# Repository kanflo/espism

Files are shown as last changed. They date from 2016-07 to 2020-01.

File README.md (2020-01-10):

# Espism

This repo contins schematics and code to build a low cost ISM radio to wifi gateway.

Look at [hardware/v4](https://github.com/kanflo/espism/tree/master/hardware/v4) for the hardware and [verification](https://github.com/kanflo/espism/tree/master/verification) for the software used to do hardware verification. The directory [mqtt_sniffer](https://github.com/kanflo/espism/tree/master/mqtt_sniffer) contains an ISM to MQTT sniffer. Blog post [is here](http://johan.kanflo.com/bridging-ism-radio-and-wifi-for-lunch-money/).

#### Building

```
git clone https://github.com/kanflo/espism.git
cd espism
git submodule init && git submodule update
cd mqtt_sniffer
vi esp-open-rtos/include/private_ssid_config.h # Fix wifi credentials
make && make flash
```

Wifi credentials, in case you did not know, are written to `esp-open-rtos/include/private_ssid_config.h` as 

```
#define WIFI_SSID "your ssid"
#define WIFI_PASS "your key"
```

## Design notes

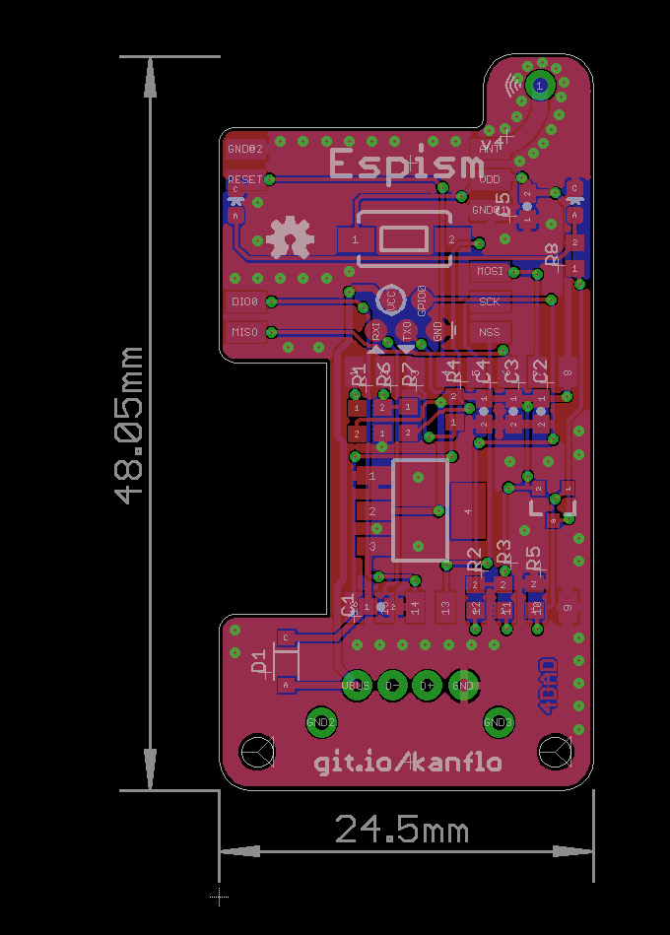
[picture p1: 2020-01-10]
hardware/v4/espism-v4.png

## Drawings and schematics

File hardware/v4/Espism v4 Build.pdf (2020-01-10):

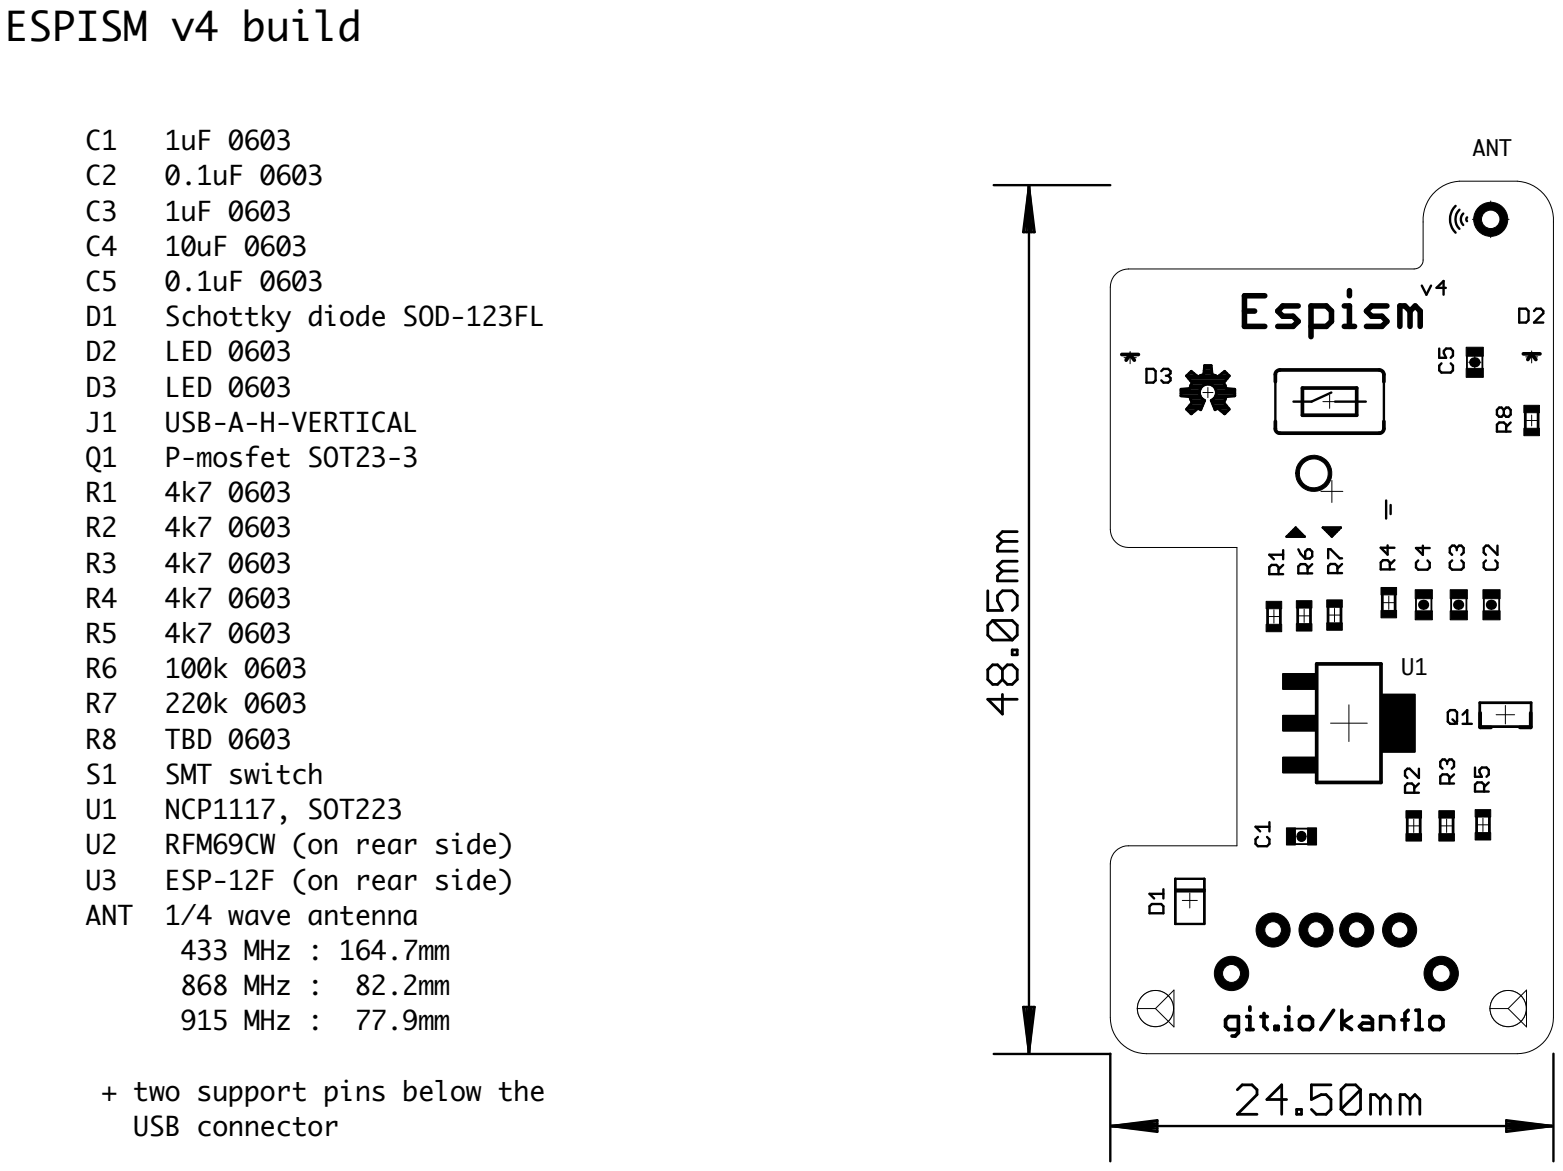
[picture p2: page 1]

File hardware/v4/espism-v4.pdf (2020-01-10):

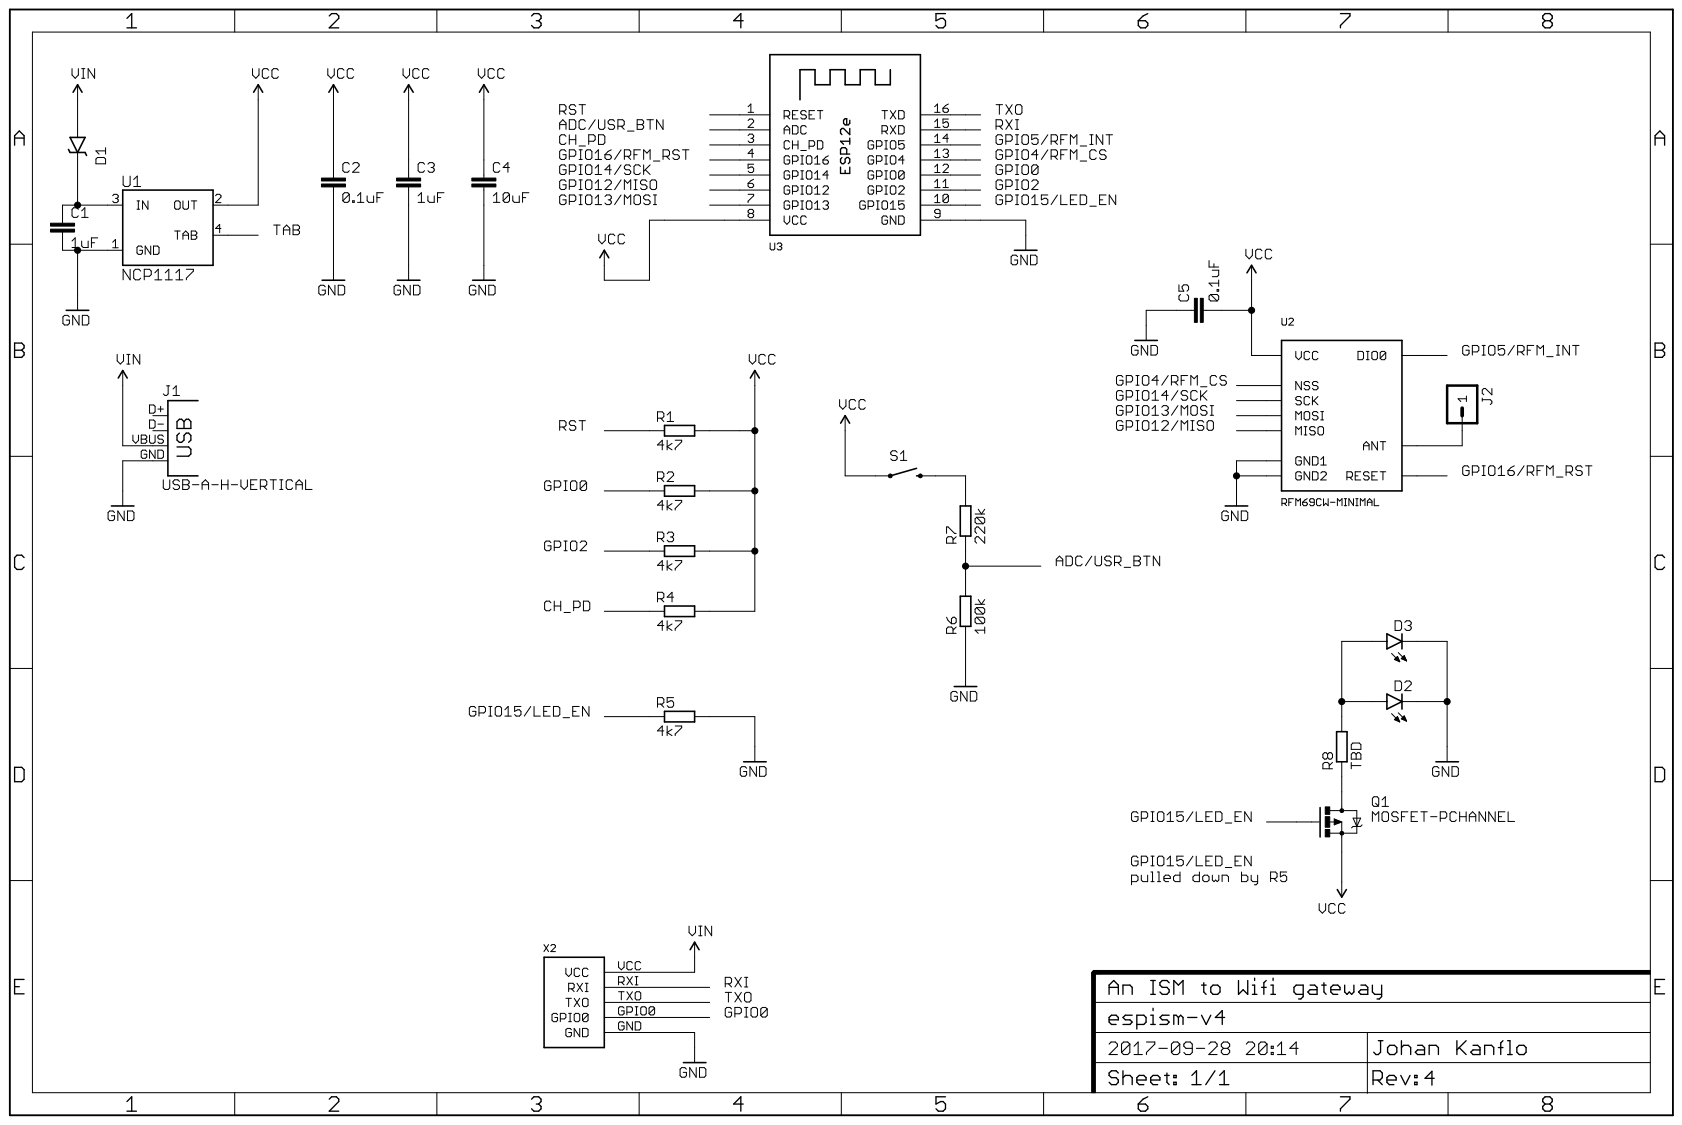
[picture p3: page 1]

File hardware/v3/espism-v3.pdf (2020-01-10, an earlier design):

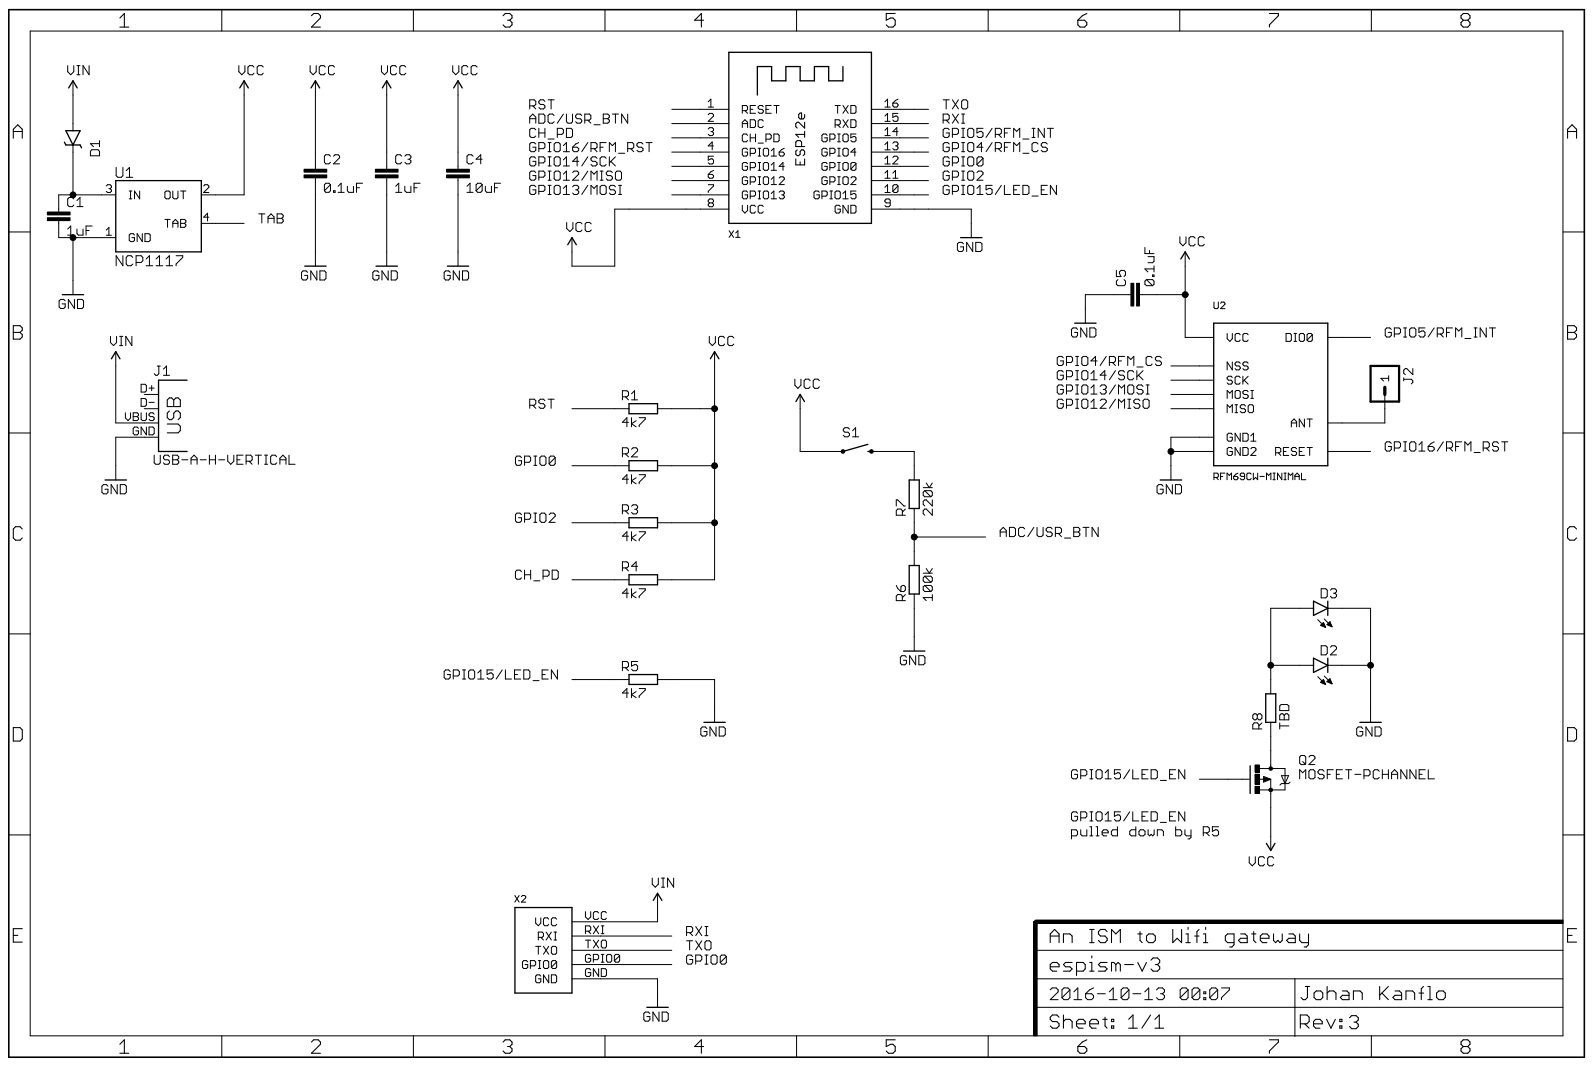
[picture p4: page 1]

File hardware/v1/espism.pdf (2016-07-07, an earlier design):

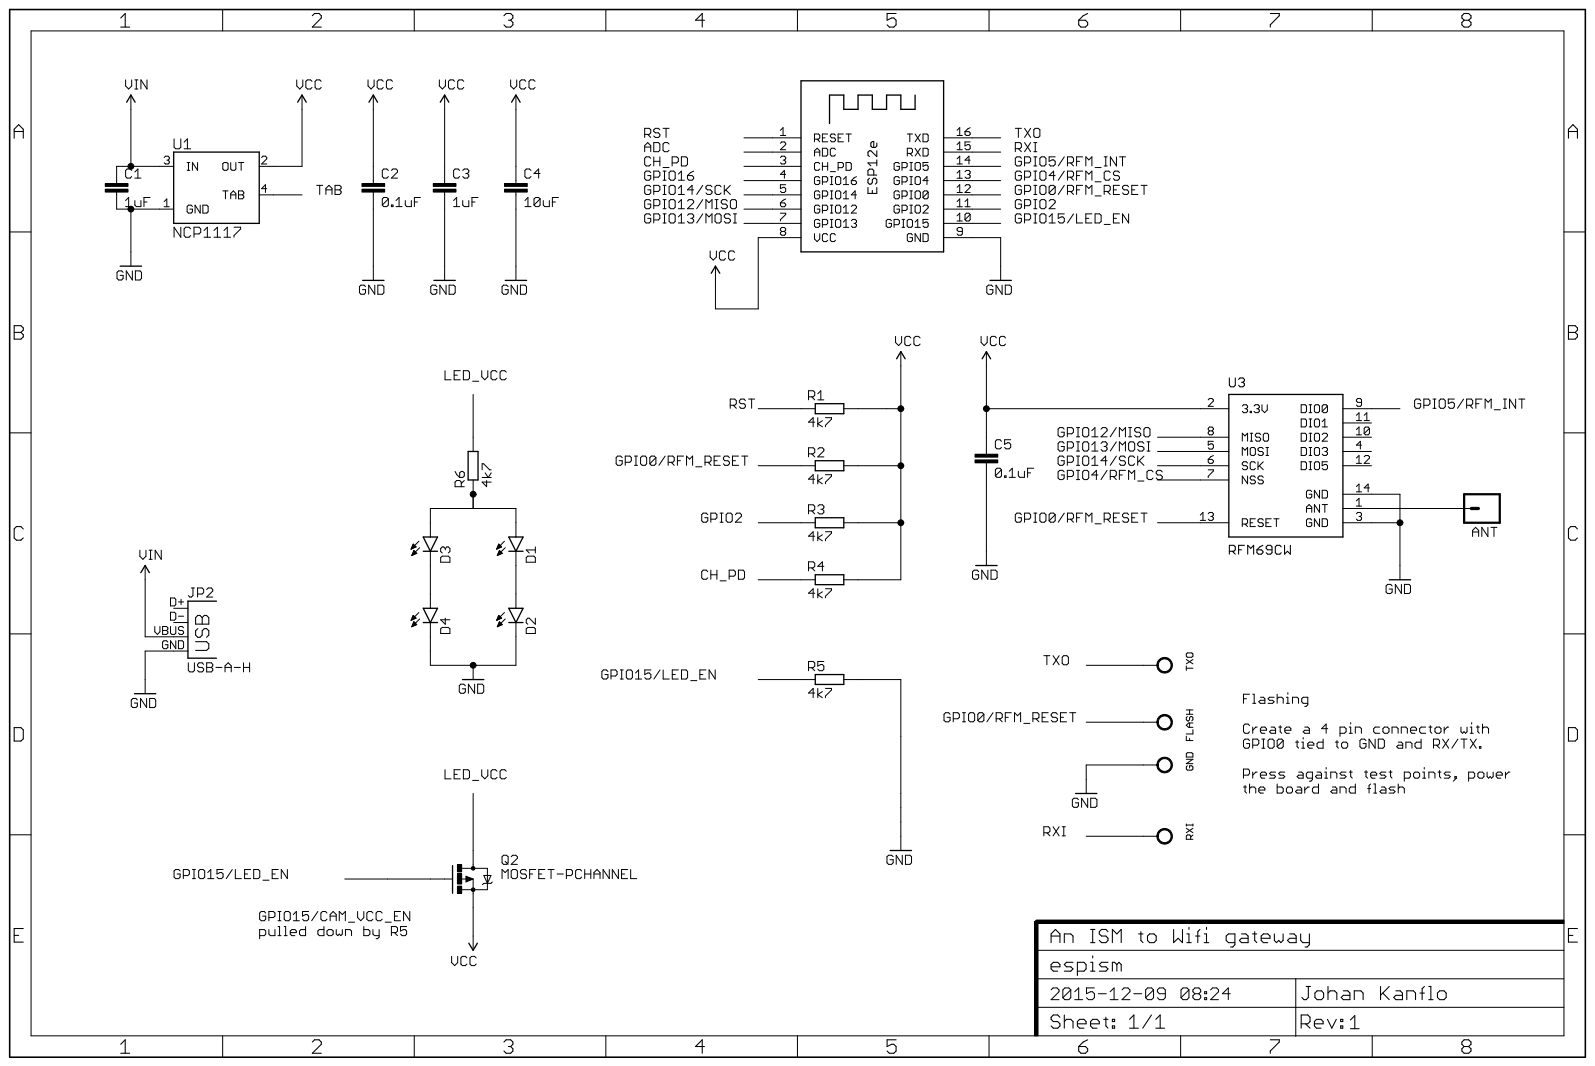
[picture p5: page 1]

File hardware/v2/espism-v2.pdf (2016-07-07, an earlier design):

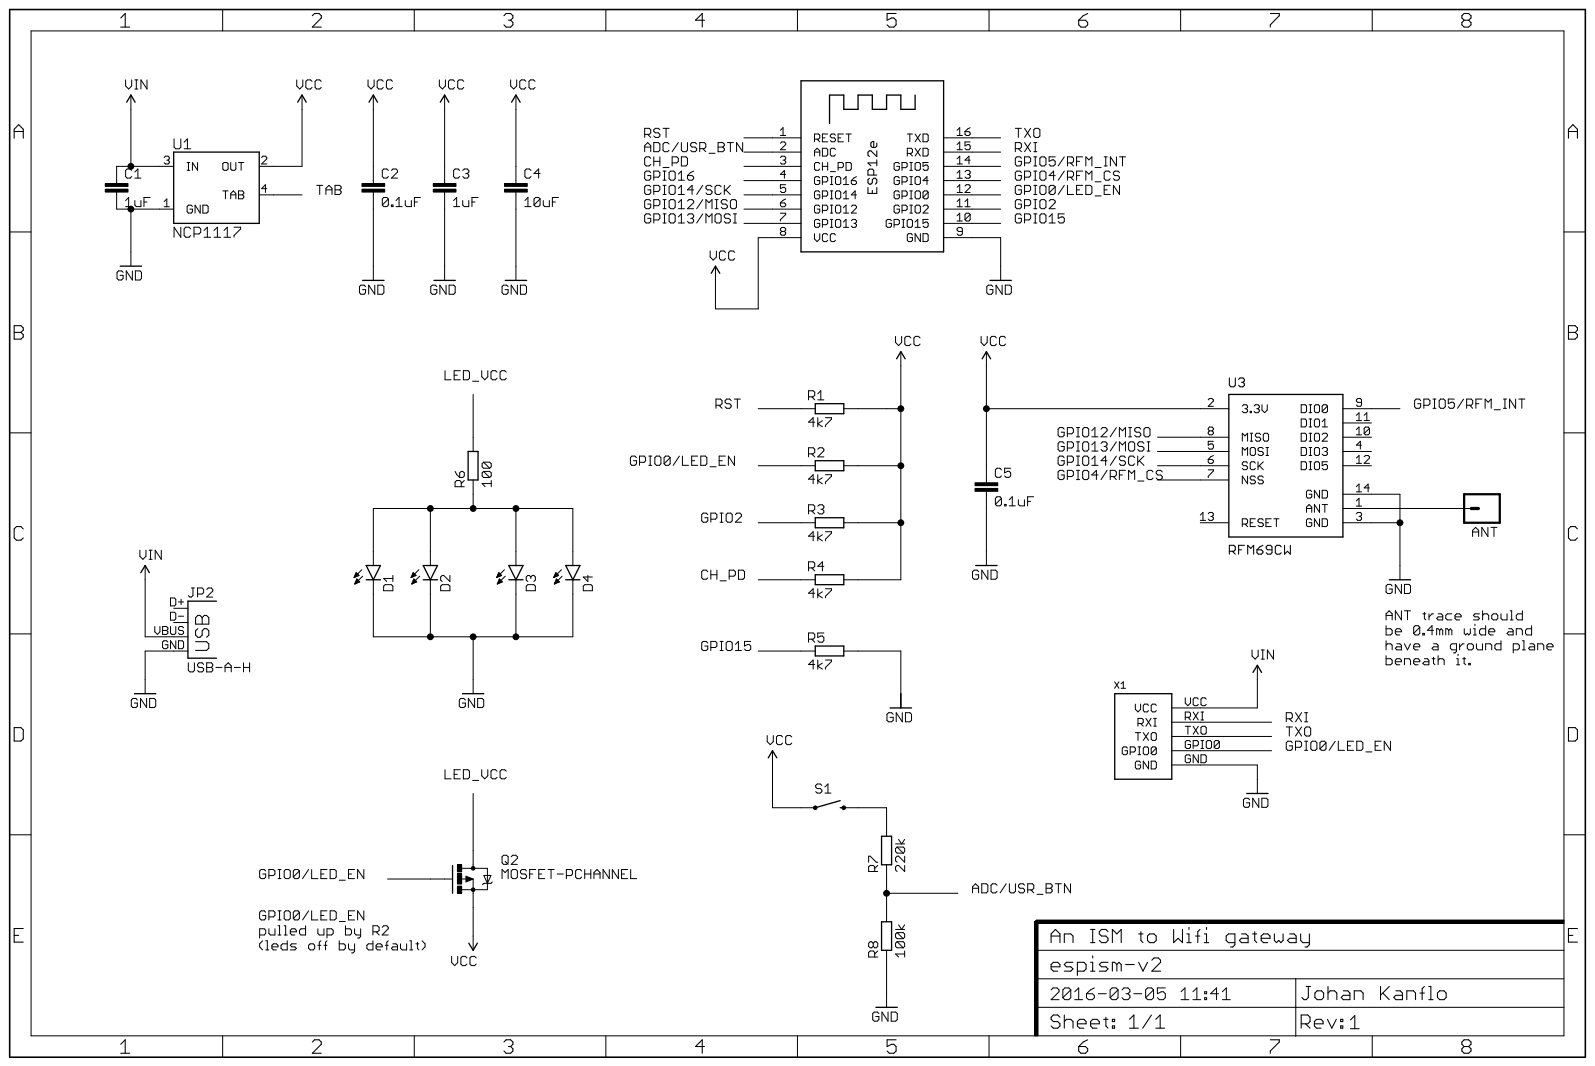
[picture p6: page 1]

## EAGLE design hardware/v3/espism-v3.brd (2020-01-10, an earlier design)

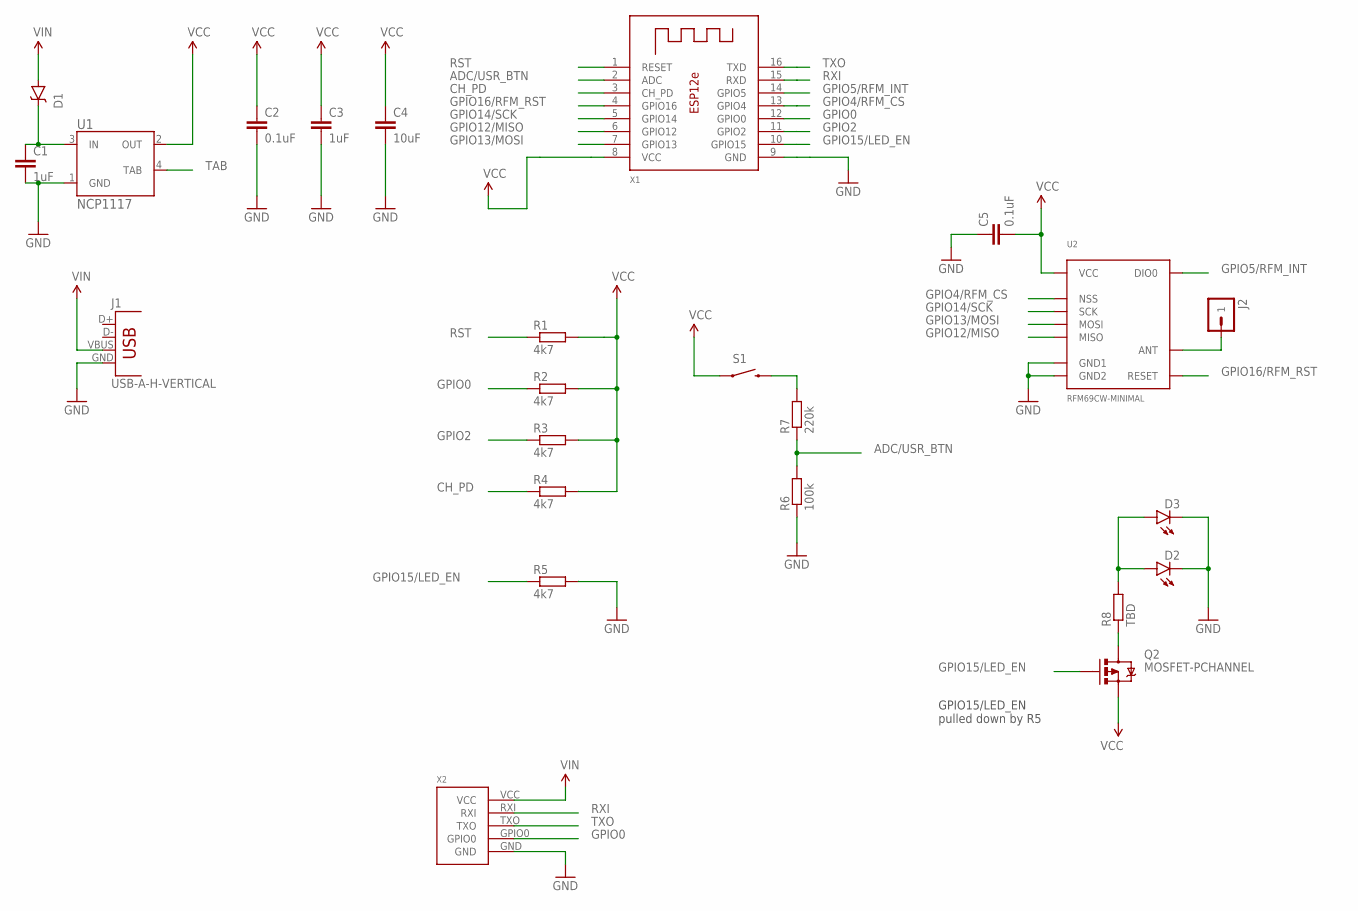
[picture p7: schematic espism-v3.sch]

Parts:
C1, C3: 1uF; 0603-CAP
C2, C5: 0.1uF; 0603-CAP
C4: 10uF; 0603-CAP
D1: DIODE-SCHOTTKYSOD-123FL; SOD-123FL
D2, D3: LED0603; LED-0603
J1: USB-A-H-VERTICAL
J2: M01-ANTENNA; 1X01-ANTENNA
Q2: MOSFET-PCHANNEL; SOT23-3
R1, R2, R3, R4, R5: 4k7; R0603
R6: 100k; R0603
R7: 220k; R0603
R8: TBD; R0603
S1: SWITCH-MOMENTARY-2SMD-1101NE; TACTILE-SWITCH-1101NE
U1: NCP1117; SOT223
U2: RFM69CW-MINIMAL
X1: ESP-12E
X2: ESPROGESPROG-DEVICE; ESPROG

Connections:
ADC/USR_BTN: R6.2, R7.1, X1.2 (ADC)
CAM_VCC: Q2.3 (D), R8.1
CH_PD: R4.1, X1.3 (CH_PD)
GND: C1.2, C2.2, C3.2, C4.2, C5.1, D2.C, D3.C, J1.GND, R5.2, R6.1, U1.1 (GND), U2.GND@1 (GND1), U2.GND@2 (GND2), X1.9 (GND), X2.GND
GPIO0: R2.1, X1.12 (GPIO0), X2.GPIO0
GPIO2: R3.1, X1.11 (GPIO2)
GPIO4/RFM_CS: U2.NSS, X1.13 (GPIO4)
GPIO5/RFM_INT: U2.DIO0, X1.14 (GPIO5)
GPIO12/MISO: U2.MISO, X1.6 (GPIO12)
GPIO13/MOSI: U2.MOSI, X1.7 (GPIO13)
GPIO14/SCK: U2.SCK, X1.5 (GPIO14)
GPIO15/LED_EN: Q2.1 (G), R5.1, X1.10 (GPIO15)
GPIO16/RFM_RST: U2.RESET, X1.4 (GPIO16)
unnamed: D2.A, D3.A, R8.2
unnamed: C1.1, D1.C, U1.3 (IN)
unnamed: J2.1, U2.ANT
unnamed: R7.2, S1.2
RST: R1.1, X1.1 (RESET)
RXI: X1.15 (RXD), X2.RXI
TAB: U1.4 (TAB)
TXO: X1.16 (TXD), X2.TXO
VCC: C2.1, C3.1, C4.1, C5.2, Q2.2 (S), R1.2, R2.2, R3.2, R4.2, S1.1, U1.2 (OUT), U2.VDD (VCC), X1.8 (VCC)
VIN: D1.A, J1.VBUS, X2.VCC

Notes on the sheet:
GPIO15/LED_EN pulled down by R5

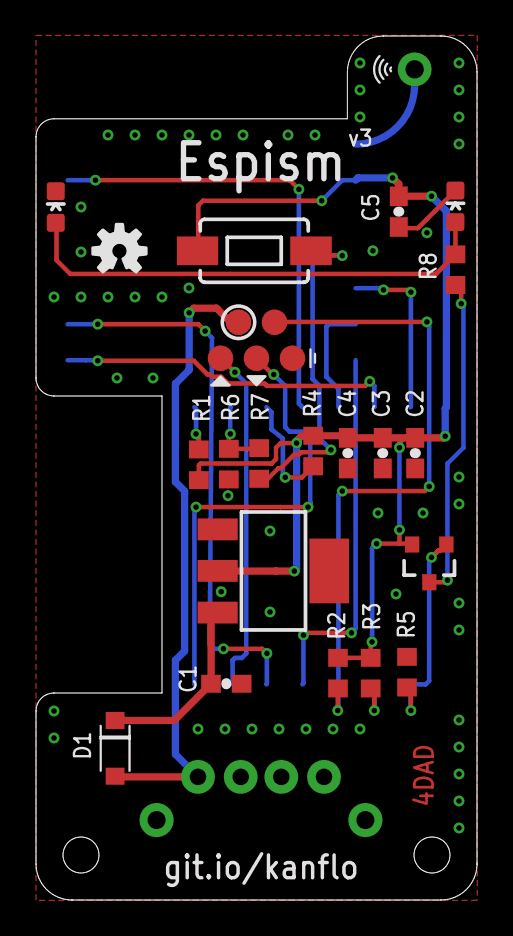
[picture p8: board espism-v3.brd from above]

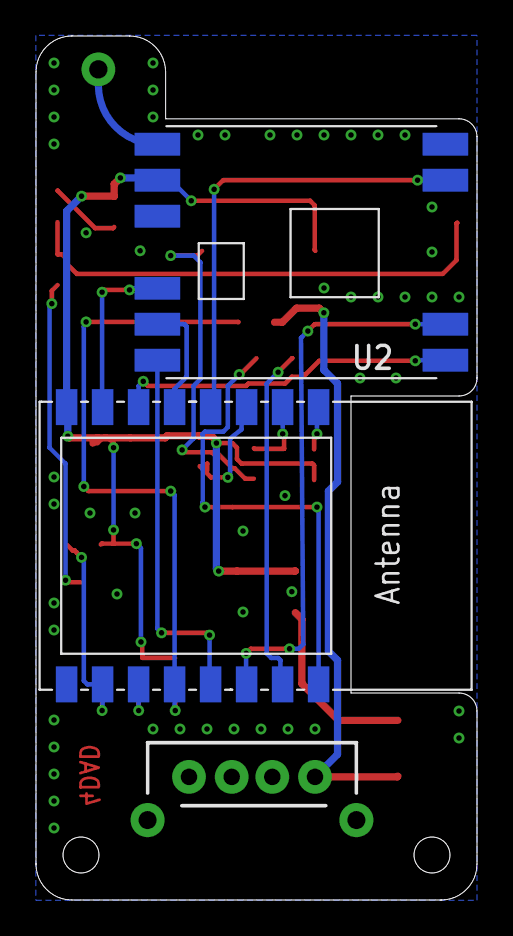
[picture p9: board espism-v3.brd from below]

Board: 2 copper layers, 24.5 x 48.0 mm, 25 parts (3 on the bottom side), 22 nets.

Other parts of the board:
U$2: OSHW-LOGO-S

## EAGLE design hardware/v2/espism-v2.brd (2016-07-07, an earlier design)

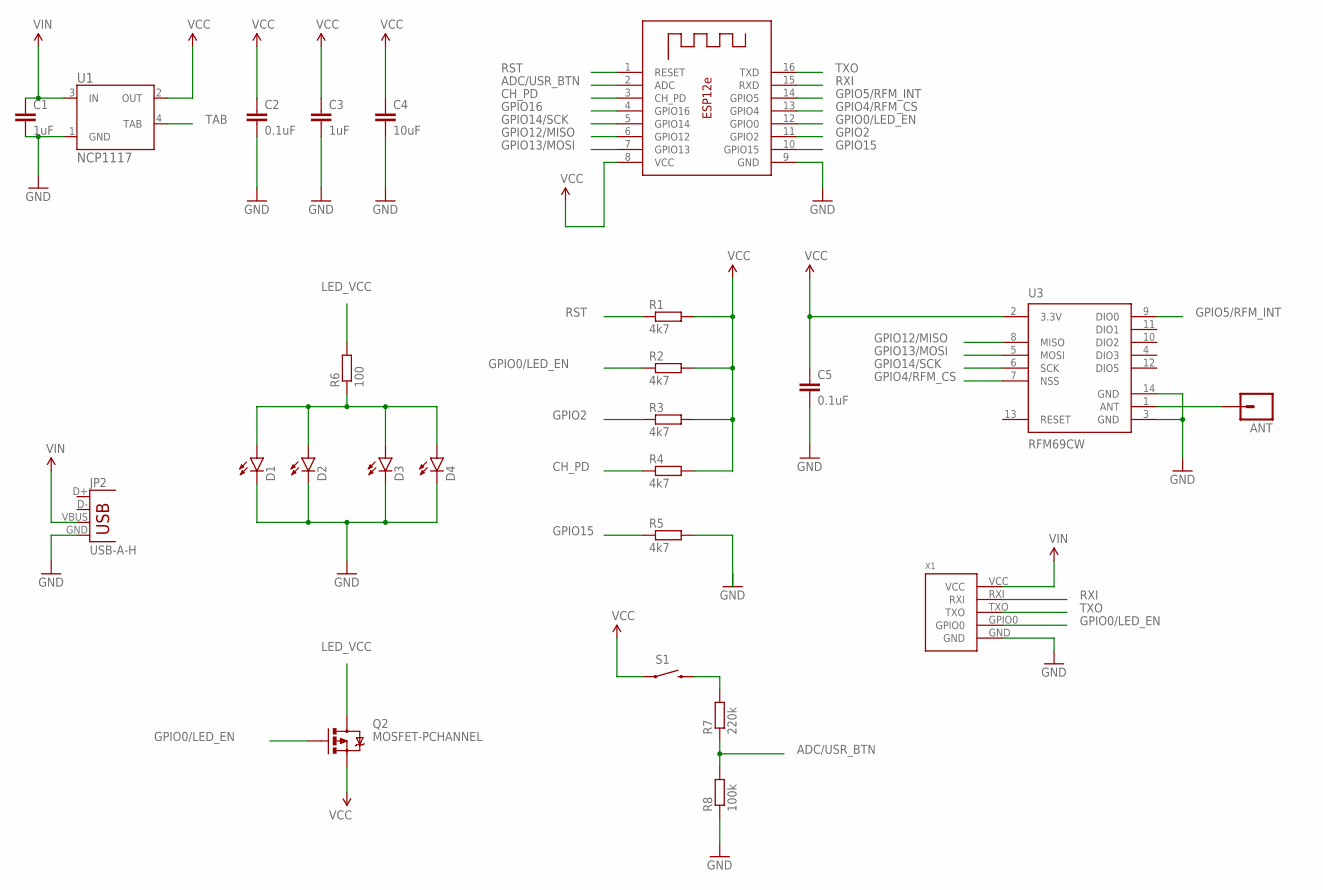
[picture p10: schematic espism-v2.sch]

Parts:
ANT: M01PTH; 1X01
C1, C3: 1uF; 0603-CAP
C2, C5: 0.1uF; 0603-CAP
C4: 10uF; 0603-CAP
D1, D2, D3, D4: LED0603; LED-0603
JP2: USB-A-H
Q2: MOSFET-PCHANNEL; SOT23-3
R1, R2, R3, R4, R5: 4k7; R0603
R6: 100; R0603
R7: 220k; R0603
R8: 100k; R0603
S1: SWITCH-MOMENTARY-2SMD-1101NE; TACTILE-SWITCH-1101NE
U1: NCP1117; SOT223
U2: ESP-12E
U3: RFM69CW; RFM69CW-XXXS2
X1: ESPROGESPROG-DEVICE; ESPROG

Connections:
ADC/USR_BTN: R7.1, R8.2, U2.2 (ADC)
CH_PD: R4.1, U2.3 (CH_PD)
GND: C1.2, C2.2, C3.2, C4.2, C5.2, D1.C, D2.C, D3.C, D4.C, JP2.GND, R5.2, R8.1, U1.1 (GND), U2.9 (GND), U3.3 (GND), U3.14 (GND), X1.GND
GPIO0/LED_EN: Q2.1 (G), R2.1, U2.12 (GPIO0), X1.GPIO0
GPIO2: R3.1, U2.11 (GPIO2)
GPIO4/RFM_CS: U2.13 (GPIO4), U3.7 (NSS)
GPIO5/RFM_INT: U2.14 (GPIO5), U3.9 (DIO0)
GPIO12/MISO: U2.6 (GPIO12), U3.8 (MISO)
GPIO13/MOSI: U2.7 (GPIO13), U3.5 (MOSI)
GPIO14/SCK: U2.5 (GPIO14), U3.6 (SCK)
GPIO15: R5.1, U2.10 (GPIO15)
GPIO16: U2.4 (GPIO16)
LED_VCC: Q2.3 (D), R6.2
unnamed: ANT.1, U3.1 (ANT)
unnamed: D1.A, D2.A, D3.A, D4.A, R6.1
unnamed: R7.2, S1.2
RST: R1.1, U2.1 (RESET)
RXI: U2.15 (RXD), X1.RXI
TAB: U1.4 (TAB)
TXO: U2.16 (TXD), X1.TXO
VCC: C2.1, C3.1, C4.1, C5.1, Q2.2 (S), R1.2, R2.2, R3.2, R4.2, S1.1, U1.2 (OUT), U2.8 (VCC), U3.2 (3.3V)
VIN: C1.1, JP2.VBUS, U1.3 (IN), X1.VCC

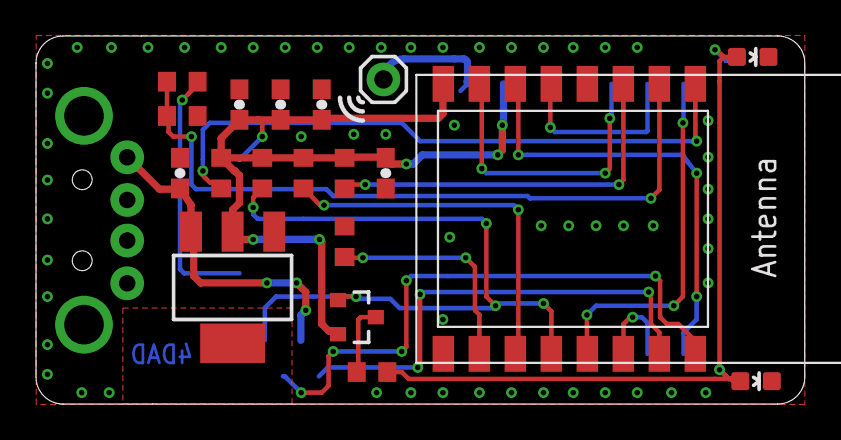
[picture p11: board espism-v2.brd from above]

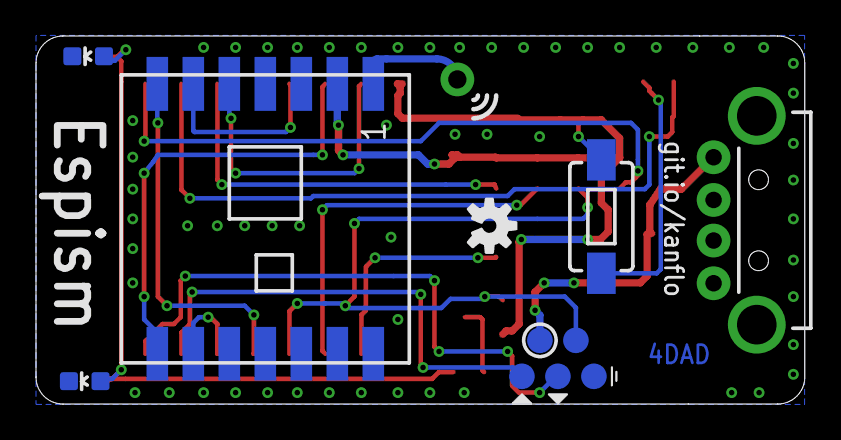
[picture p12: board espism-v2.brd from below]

Board: 2 copper layers, 42.7 x 20.4 mm, 26 parts (7 on the bottom side), 20 nets.

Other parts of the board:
U$1: OSHW-LOGO-S

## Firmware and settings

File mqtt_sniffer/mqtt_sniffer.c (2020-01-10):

/* 
 * The MIT License (MIT)
 * 
 * Copyright (c) 2016 Johan Kanflo (github.com/kanflo)
 * 
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
 * THE SOFTWARE IS PROVIDED "AS IS", WITHOUT WARRANTY OF ANY KIND, EXPRESS OR
 * IMPLIED, INCLUDING BUT NOT LIMITED TO THE WARRANTIES OF MERCHANTABILITY,
 * FITNESS FOR A PARTICULAR PURPOSE AND NONINFRINGEMENT. IN NO EVENT SHALL THE
 * AUTHORS OR COPYRIGHT HOLDERS BE LIABLE FOR ANY CLAIM, DAMAGES OR OTHER
 * LIABILITY, WHETHER IN AN ACTION OF CONTRACT, TORT OR OTHERWISE, ARISING FROM,
 * OUT OF OR IN CONNECTION WITH THE SOFTWARE OR THE USE OR OTHER DEALINGS IN
 * THE SOFTWARE.
 */

#include <esp8266.h>
#include <espressif/esp_common.h>
#include <esp/uart.h>
#include <stdio.h>
#include <stdint.h>
#include <sys/types.h>
#include <stdlib.h>
#include <unistd.h>
#include <string.h>
#include <esp/spi.h>
#include <rfm69.h>
#include <ssid_config.h>
#include <FreeRTOS.h>
#include <semphr.h>
#include <task.h>
#include <timers.h>
#include <queue.h>
#include <ota-tftp.h>
#include <rboot-integration.h>
#include <rboot.h>
#include <rboot-api.h>
#include <paho_mqtt_c/MQTTESP8266.h>
#include <paho_mqtt_c/MQTTClient.h>

typedef enum {
    led_off = 0,
    led_flash_once,
    led_flash_double,
    led_flash_slow,
    led_flash_fast
} led_state_t;


#define HW_REV CONFIG_HW_REV

/** The various espism boards I have build */
#if HW_REV==1
 #define LED_GPIO      (15)
 #define RFM69_INT      (5)
 #define RFM69_CS       (4)
#elif HW_REV==2
 #define LED_GPIO       (0)
 #define RFM69_INT      (5)
 #define RFM69_CS       (4)
#elif HW_REV==3
 #define LED_GPIO      (15)
 #define RFM69_INT      (5)
 #define RFM69_CS       (4)
 #define RFM69_RESET   (16) // Only on v3
#elif HW_REV==4
 #define LED_GPIO      (15)
 #define RFM69_INT      (5)
 #define RFM69_CS       (4)
 #define RFM69_RESET   (16) // Only on v4
#else
 #error "Unsupported HW revision"
#endif


#define MAX_ISM_PKT_SIZE  (64)
#define PUB_QUEUE_DEPTH   (10)

#define MQTT_HOST CONFIG_MQTT_HOST
#define MQTT_PORT CONFIG_MQTT_PORT

#ifdef CONFIG_MQTT_USER
 #define MQTT_USER CONFIG_MQTT_USER
#else // CONFIG_MQTT_USER
 #define MQTT_USER NULL
#endif // CONFIG_MQTT_USER

#ifdef CONFIG_MQTT_PASS
 #define MQTT_PASS CONFIG_MQTT_PASS
#else // CONFIG_MQTT_PASS
 #define MQTT_PASS NULL
#endif // CONFIG_MQTT_PASS

#define RFM_KEY CONFIG_RFM_KEY

SemaphoreHandle_t wifi_alive;
SemaphoreHandle_t sniffer_alive;
QueueHandle_t publish_queue;

volatile led_state_t g_led_state = led_off;

#define delay_ms(ms) vTaskDelay(ms / portTICK_PERIOD_MS)

static const char* get_station_mac(void);
static const char* get_station_ip(void);

static void set_led(bool on)
{
    gpio_write(LED_GPIO, on?0:1);
}

static void set_led_state(led_state_t state)
{
    g_led_state = state;
}

static void heartbeat_task(void *param)
{
    (void) param;
    char msg[MAX_ISM_PKT_SIZE];
    while(1) {
        delay_ms(60000);
        printf("Publishing heartbeat\n");
#if 0
        /** Currently cannot do this as the entries in the queue are RFM
         *  packets and not arbitrary strings
         */
        snprintf(msg, sizeof(msg)-1, "heartbeat:%s", get_station_ip());
#else
        memset(msg, 0, sizeof(msg));
#endif
        if (xQueueSend(publish_queue, (void*) msg, 0) == pdFALSE) {
            printf("Publish queue overflow.\n");
        }
    }
}

static void led_task(void *pvParameters)
{
    while(1) {
        switch(g_led_state) {
            case led_off:
                delay_ms(100); // Do not while(1). Todo: Use semaphore
                break;
            case led_flash_once:
                set_led(1);  delay_ms(50);
                set_led(0);
                g_led_state = led_off;
                break;
            case led_flash_double:
                set_led(1); delay_ms(50);
                set_led(0); delay_ms(250);
                set_led(1); delay_ms(50);
                set_led(0); delay_ms(950);
                break;
            case led_flash_fast:
                set_led(1); delay_ms(10);
                set_led(0); delay_ms(450);
                break;
            case led_flash_slow:
                set_led(1); delay_ms(500);
                set_led(0); delay_ms(500);
                break;
        }
    }
}

static bool ism_init()
{
    static bool init = false;
    if (init) {
        return true;
    }
    init = true;
#ifdef RFM69_RESET
    rfm69_setResetPin(RFM69_RESET);
    rfm69_reset();
#endif // RFM69_RESET

    spi_init(1, SPI_MODE0, SPI_FREQ_DIV_1M, 1, SPI_LITTLE_ENDIAN, true);
    /** true = RFM69HW, false = RFM69W */
    bool ok = rfm69_init(RFM69_CS, false);
    if (!ok) {
        printf("RFM69 init failed!\n");
        set_led_state(led_flash_slow);
        return false;
    } else {
        printf("RFM69 init ok\n");
        gpio_enable(RFM69_INT, GPIO_INPUT);
        rfm69_sleep();
        /** set output power, +10 dBm */
        rfm69_setPowerDBm(10);
        /** enable CSMA/CA algorithm */
        rfm69_setCSMA(true);
        rfm69_setAutoReadRSSI(true);
        (void) rfm69_setAESEncryption((void*) RFM_KEY, 16);
        rfm69_setPowerLevel(0); // max 31
    }
    return true;
}

static void ism_task(void *pvParameters)
{
    if (!ism_init()) {
        return;
    }
    while(1) {
        xSemaphoreTake(sniffer_alive, portMAX_DELAY);
        uint8_t data[MAX_ISM_PKT_SIZE];
        memset(data, 0, MAX_ISM_PKT_SIZE);
        int len = rfm69_receive((char*) data, MAX_ISM_PKT_SIZE);
        if (len > 0) {
            set_led_state(led_flash_once);
            int rssi = rfm69_getRSSI();
            data[0] = len+1; // [len data[0] data[1] ... data[len-1] rssi]
            data[len] = (int8_t) rssi;
//            rfm69_sleep();
            if (xQueueSend(publish_queue, (void*) data, 0) == pdFALSE) {
                printf("Publish queue overflow.\n");
            }
        }
        xSemaphoreGive(sniffer_alive);
    }
}

// Return our IP address as a string "a.b.c.d" or "0.0.0.0" if we cannot determine it
static const char* get_station_ip(void)
{
    static char ip[16] = "0.0.0.0";
    ip[0] = 0;
    struct ip_info ipinfo;
    (void) sdk_wifi_get_ip_info(STATION_IF, &ipinfo);
    snprintf(ip, sizeof(ip), IPSTR, IP2STR(&ipinfo.ip));
    return (char*) ip;
}

// Use MAC address for Station as unique ID
static const char* get_station_mac(void)
{
    static char my_id[32];
    static bool my_id_done = false;
    uint8_t hwaddr[6];
    if (my_id_done)
        return my_id;
    if (!sdk_wifi_get_macaddr(STATION_IF, (uint8_t*)hwaddr))
        return NULL;
    snprintf(my_id, sizeof(my_id), "%02x%02x%02x%02x%02x%02x", MAC2STR(hwaddr));
    my_id_done = true;
    return my_id;
}
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

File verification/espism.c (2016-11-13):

/* 
 *
 * This application is used for hardware verification of the Espisn board. Build, flash, boot and type 'help'.
 * Oh, the UART runs at 115200 baud.
 */

#include "espressif/esp_common.h"
#include "esp/uart.h"

#include <stdint.h>
#include <sys/types.h>
#include <stdlib.h>
#include <unistd.h>
#include <string.h>
#include <esp8266.h>
#include <esp/uart.h>
#include <stdio.h>
#include <spi.h>
#include <rfm69.h>

#include "FreeRTOS.h"
#include "task.h"
#include "timers.h"
#include "queue.h"
#include "ota-tftp.h"
#include "rboot-integration.h"
#include "rboot.h"
#include "rboot-api.h"


#define HW_REV   (2) // 1..3

#if HW_REV==1
 #define LED_GPIO      (15)
 #define RFM69_INT      (5)
 #define RFM69_CS       (4)
#elif HW_REV==2
 #define LED_GPIO       (0)
 #define RFM69_INT      (5)
 #define RFM69_CS       (4)
#elif HW_REV==3
 #define LED_GPIO      (15)
 #define RFM69_INT      (5)
 #define RFM69_CS       (4)
 #define RFM69_RESET   (16) // Only on v3
#else
 #error "Unsupported HW revision"
#endif

#define LOOP_DELAY_MS 2000

#define MAX_ARGC (10)

#define delay_ms(ms) vTaskDelay(ms / portTICK_RATE_MS)

static bool adc_display = false;
static bool btn_display = false;
static bool rx_display = false;
static bool tx_display = false;

static void set_led(bool on)
{
    gpio_write(LED_GPIO, on?0:1);
}

static bool button_pressed()
{
    uint16_t val = sdk_system_adc_read();
    return val > 100;
}

static bool ism_init()
{
    static bool init = false;
    if (init) {
        return true;
    }
    init = true;
#ifdef RFM69_RESET
    rfm69_setResetPin(RFM69_RESET);
    rfm69_reset();
#endif // RFM69_RESET

    spi_init(iHSPI);
    bool ok = rfm69_init(RFM69_CS, false); // false = RFM69W, true = RFM69HW

    if (!ok) {
        printf("RFM69 init failed!\n");
        return false;
    } else {
        printf("RFM69 init ok\n");
        gpio_enable(RFM69_INT, GPIO_INPUT);
        rfm69_sleep(); // init RF module and put it to sleep
        rfm69_setPowerDBm(10); // // set output power, +10 dBm
        rfm69_setCSMA(true); // enable CSMA/CA algorithm
        rfm69_setAutoReadRSSI(true);
        (void) rfm69_setAESEncryption((void*) "sampleEncryptKey", 16);
        rfm69_setPowerLevel(31); // max 31
    }
    return true;
}

static bool cmd_adc(uint32_t argc, char *argv[])
{
    if (argc == 1) {
        uint16_t val = sdk_system_adc_read();
        printf("adc %d\n", val);
    } else if (argc == 2) {
        adc_display = strcmp(argv[1], "on") == 0;
    } else {
        return false;
    }
    return true;
}

static bool cmd_led(uint32_t argc, char *argv[])
{
    if (argc == 2) {
        set_led(strcmp(argv[1], "on") == 0);
    } else {
        return false;
    }
    return true;
}

static bool cmd_button(uint32_t argc, char *argv[])
{
    if (argc == 1) {
        printf("Button is %spressed\n", button_pressed() ? "" : "not ");
    } else if (argc == 2) {
        btn_display = strcmp(argv[1], "on") == 0;
    } else {
        return false;
    }
    return true;
}

static bool cmd_ism_init(uint32_t argc, char *argv[])
{
    return ism_init();
}

static bool cmd_rx(uint32_t argc, char *argv[])
{
    if (argc == 1) {
        // send a packet and let RF module sleep
        if (ism_init()) {
            char data[32];
            memset(data, 0, sizeof(data));
            int len = rfm69_receive(data, sizeof(data));
            if (len > 0) {
                int rssi = rfm69_getRSSI();
                set_led(true);
                rfm69_sleep();
                printf("Got %d bytes :", len);
                for (int i=0; i<len; i++) {
                    printf(" %02x", data[i]);
                }
                printf(" [%-3d]\n", rssi);
                set_led(false);
            }
        }
    } else if (argc == 2) {
        rx_display = strcmp(argv[1], "on") == 0;
        printf("yes:%d\n", rx_display);
    } else {
        return false;
    }
    return true;
}

static bool cmd_tx(uint32_t argc, char *argv[])
{
    if (argc == 1) {
        // send a packet and let RF module sleep
        char testdata[] = {1, 42, 0x00, 'H', 'e', 'l', 'l', 'o', ' ', 'W', 'o', 'r', 'l', 'd', '!'};
        if (ism_init()) {
            set_led(true);
            rfm69_send(testdata, sizeof(testdata));
            set_led(false);
            rfm69_sleep();
            printf("Message sent\n");
        }
    } else if (argc == 2) {
        tx_display = strcmp(argv[1], "on") == 0;
    } else {
        return false;
    }
    return true;
}

static bool cmd_write_register(uint32_t argc, char *argv[])
{
    if (argc == 3) {
        uint32_t reg = atoi(argv[1]);
        uint32_t val = atoi(argv[2]);
        printf("%x = %d\n", reg, val);
        rfm69_writeRegister(reg, val);
        return true;
    } else {
        return false;
    }
}

static bool cmd_read_register(uint32_t argc, char *argv[])
{
    if (argc == 2) {
        uint32_t reg = atoi(argv[1]);
        printf("[%d] == 0x%x\n", reg, rfm69_readRegister(reg));
        return true;
    } else {
        return false;
    }
}

static bool cmd_dump_registers(uint32_t argc, char *argv[])
{
    rfm69_dumpRegisters();        
    return true;
}

static bool cmd_help(uint32_t argc, char *argv[])
{
    printf(
        "adc [<on|off>]      Print adc value or start/stop polling\n"
        "led <on|off>        Control LED\n"
        "button [<on|off>]   Print button value or start/stop polling\n"
        "init                Initialize RFM69CW\n"
        "tx                  TX one packet\n"
        "rx                  RX one packet\n"
        "registers           Dump RFM69CW registers\n"
        "w <reg> <value>     Write RFM69CW register\n"
        "r <reg>             Read RFM69CW register\n"
    );
    return true;
}
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

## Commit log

2016-10-12 Updated after MQTT rename Changed MQTT broker to iot.eclipse.org
    [mqtt_sniffer.c]
2016-11-13 Corrected HW revision in schematics
    [espism-v2.sch]
2020-01-10 Updated to latest EOR EOR now a submodule RFM69 driver now a submodule Removed legacy SPI driver
2020-01-10 HW rev 3 and 4
    [espism-v3.brd, espism-v3.sch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]

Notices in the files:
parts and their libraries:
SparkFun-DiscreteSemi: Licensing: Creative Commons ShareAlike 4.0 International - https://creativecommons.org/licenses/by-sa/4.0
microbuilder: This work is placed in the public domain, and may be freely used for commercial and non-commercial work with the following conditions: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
